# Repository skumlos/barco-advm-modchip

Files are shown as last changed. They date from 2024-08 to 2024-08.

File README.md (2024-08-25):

Arduino Mini Pro clone with Atmega328PB, Barco Edition

This is basically an Arduino Mini Pro clone but with an Atmega328PB instead of Atmega328P.
The generic components that are needed when modding Barco ADVM monitors have been added
to make the mod "prettier".

Speed 16MHz and 5V.

The reasoning is to have the secondary I2C controller of the PB version, thus PE0 and PE1
pins are pulled to 2.54mm THT holes just like A4/A5 pins of the primary I2C controller.
These are then connected to the buffer already so no extra breakout PCB and intermediate
resistors are needed.

It is still recommended to add a 100R resistor to SDA and SCL lines right at the pads of
the original resistors on the signal PCB.

Remember to burn a bootloader and fuses with a *real* programmer (like another Arduino
turned into an ISP). This requires you to connect to the ICSP pins, MOSI, MISO, SCK,
RESET, 5V and GND. I used a male pin header row  which I didn't solder but just held in
place during programming.

(2024) Martin Hejnfelt, martin@hejnfelt.com

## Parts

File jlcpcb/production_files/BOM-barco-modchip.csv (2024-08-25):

Comment | Designator | Footprint | LCSC
100R | R40,R41,R42,R43 | R_0603_1608Metric | C105588
330R | R10 | R_0603_1608Metric | C105881
2.7k | R50,R51 | R_0603_1608Metric | C114612
ATMEGA328PB-AU | U1 | TQFP-32_7x7mm_P0.8mm | C132230
100nF | C10,C12,C13,C41 | C_0603_1608Metric | C14663
1k | R30,R31 | R_0603_1608Metric | C22548
RED_LED | D20 | LED_0603_1608Metric | C2286
10K | R11,R20 | R_0603_1608Metric | C25804
SW_SPST | SW1 | SW_Tactile_SPST_NO_Straight_CK_PTS636Sx25SMTRLFS | C2689642
74LVC2G34 | U40 | SOT-23-6 | C347589
MIC5205-5.0YM5 | U20 | SOT-23-5 | C70431
10uF | C20,C21 | CP_EIA-3216-18_Kemet-A | C7171
GRN_LED | D10 | LED_0603_1608Metric | C72038
CSTNE16M0VH3L000R0 | Y1 | Resonator_SMD_Murata_CSTxExxV-3Pin_3.0x1.1mm | C882605
Conn_01x12_Female | J11 | PinHeader_1x12_P2.54mm_Vertical
Conn_01x06 | J2 | PinHeader_1x06_P2.54mm_Horizontal
Conn_01x12_Female | J10 | PinHeader_1x12_P2.54mm_Vertical
Conn_01x02_Female | J12 | PinHeader_1x02_P2.54mm_Vertical
Conn_01x02_Female | J14 | PinHeader_1x02_P2.54mm_Vertical
Conn_01x02_Female | J13 | PinHeader_1x02_P2.54mm_Vertical
Blanking | J30 | TestPoint_THTPad_D2.0mm_Drill1.0mm
MONITOR_I2C | J40 | PinHeader_1x02_P2.54mm_Vertical

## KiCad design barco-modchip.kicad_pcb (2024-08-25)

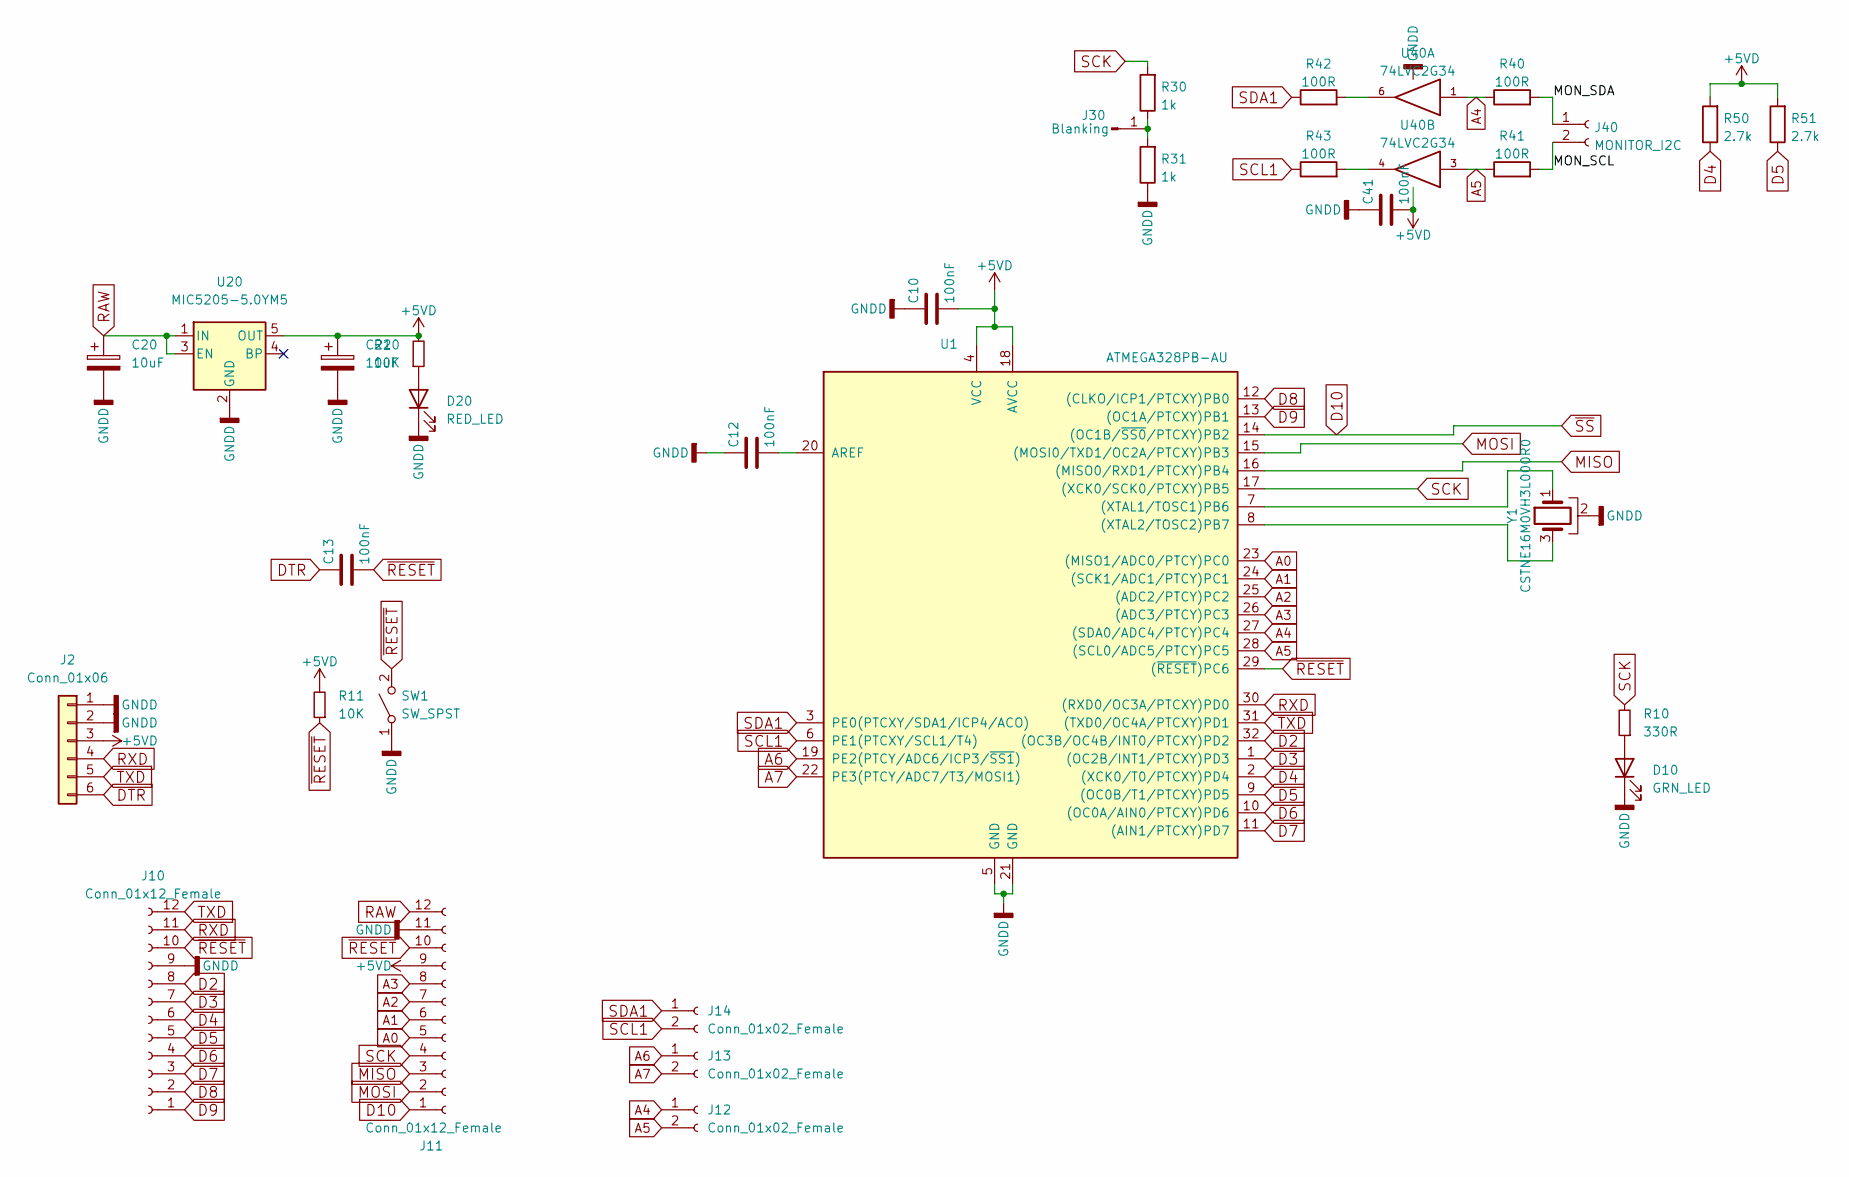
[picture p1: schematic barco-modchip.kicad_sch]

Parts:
C10, C12, C13, C41: 100nF; C_0603_1608Metric
C20, C21: 10uF; CP_EIA-3216-18_Kemet-A
D10: GRN_LED; LED_0603_1608Metric
D20: RED_LED; LED_0603_1608Metric
J2: Conn_01x06; PinHeader_1x06_P2.54mm_Horizontal
J10, J11: Conn_01x12_Female; PinHeader_1x12_P2.54mm_Vertical
J12, J13, J14: Conn_01x02_Female; PinHeader_1x02_P2.54mm_Vertical
J30: Blanking; TestPoint_THTPad_D2.0mm_Drill1.0mm
J40: MONITOR_I2C; PinHeader_1x02_P2.54mm_Vertical
R10: 330R; R_0603_1608Metric
R11, R20: 10K; R_0603_1608Metric
R30, R31: 1k; R_0603_1608Metric
R40, R41, R42, R43: 100R; R_0603_1608Metric
R50, R51: 2.7k; R_0603_1608Metric
SW1: SW_SPST; SW_Tactile_SPST_NO_Straight_CK_PTS636Sx25SMTRLFS
U1: ATMEGA328PB-AU; TQFP-32_7x7mm_P0.8mm
U20: MIC5205-5.0YM5; SOT-23-5
U40: 74LVC2G34; SOT-23-6
Y1: CSTNE16M0VH3L000R0; Resonator_SMD_Murata_CSTxExxV-3Pin_3.0x1.1mm

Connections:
+5VD: C10.2, C21.1, C41.2, J2.3, J11.9, R11.2, R20.2, R50.2, R51.2, U1.4 (VCC), U1.18 (AVCC), U20.5 (OUT), U40.5 (VCC)
/MON_SCL: J40.2, R41.2
/MON_SDA: J40.1, R40.2
A0: J11.5, U1.23 ((MISO1/ADC0/PTCY)PC0)
A1: J11.6, U1.24 ((SCK1/ADC1/PTCY)PC1)
A2: J11.7, U1.25 ((ADC2/PTCY)PC2)
A3: J11.8, U1.26 ((ADC3/PTCY)PC3)
A4: J12.1, R40.1, U1.27 ((SDA0/ADC4/PTCY)PC4), U40.1
A5: J12.2, R41.1, U1.28 ((SCL0/ADC5/PTCY)PC5), U40.3
A6: J13.1, U1.19 (PE2(PTCY/ADC6/ICP3/~SS1))
A7: J13.2, U1.22 (PE3(PTCY/ADC7/T3/MOSI1))
D2: J10.8, U1.32 ((OC3B/OC4B/INT0/PTCXY)PD2)
D3: J10.7, U1.1 ((OC2B/INT1/PTCXY)PD3)
D4: J10.6, R50.1, U1.2 ((XCK0/T0/PTCXY)PD4)
D5: J10.5, R51.1, U1.9 ((OC0B/T1/PTCXY)PD5)
D6: J10.4, U1.10 ((OC0A/AIN0/PTCXY)PD6)
D7: J10.3, U1.11 ((AIN1/PTCXY)PD7)
D8: J10.2, U1.12 ((CLKO/ICP1/PTCXY)PB0)
D9: J10.1, U1.13 ((OC1A/PTCXY)PB1)
D10: J11.1, U1.14 ((OC1B/~SS0/PTCXY)PB2)
DTR: C13.1, J2.6
GND: C10.1, C12.1, C20.2, C21.2, C41.1, D10.1 (K), D20.1 (K), J2.1, J2.2, J10.9, J11.11, R31.1, SW1.1 (A), U1.5 (GND), U1.21 (GND), U20.2 (GND), U40.2 (GND), Y1.2
MISO: J11.3, U1.16 ((MISO0/RXD1/PTCXY)PB4)
MOSI: J11.2, U1.15 ((MOSI0/TXD1/OC2A/PTCXY)PB3)
unnamed: C12.2, U1.20 (AREF)
unnamed: D10.2 (A), R10.1
unnamed: D20.2 (A), R20.1
unnamed: J30.1, R30.1, R31.2
unnamed: R42.2, U40.6
unnamed: R43.2, U40.4
unnamed: U1.7 ((XTAL1/TOSC1)PB6), Y1.1
unnamed: U1.8 ((XTAL2/TOSC2)PB7), Y1.3
RAW: C20.1, J11.12, U20.1 (IN), U20.3 (EN)
RXD: J2.4, J10.11, U1.30 ((RXD0/OC3A/PTCXY)PD0)
SCK: J11.4, R10.2, R30.2, U1.17 ((XCK0/SCK0/PTCXY)PB5)
SCL1: J14.2, R43.1, U1.6 (PE1(PTCXY/SCL1/T4))
SDA1: J14.1, R42.1, U1.3 (PE0(PTCXY/SDA1/ICP4/ACO))
TXD: J2.5, J10.12, U1.31 ((TXD0/OC4A/PTCXY)PD1)
~RESET: C13.2, J10.10, J11.10, R11.1, SW1.2 (B), U1.29 ((~RESET)PC6)

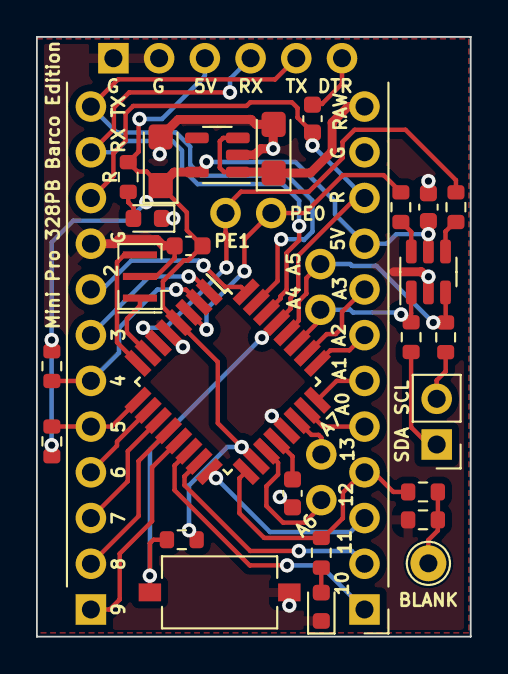
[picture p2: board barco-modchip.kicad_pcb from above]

Board: 2 copper layers, 24.1 x 33.3 mm, 32 parts (0 on the bottom side), 39 nets.
